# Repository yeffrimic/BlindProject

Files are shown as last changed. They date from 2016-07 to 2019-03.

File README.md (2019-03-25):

# Blind project

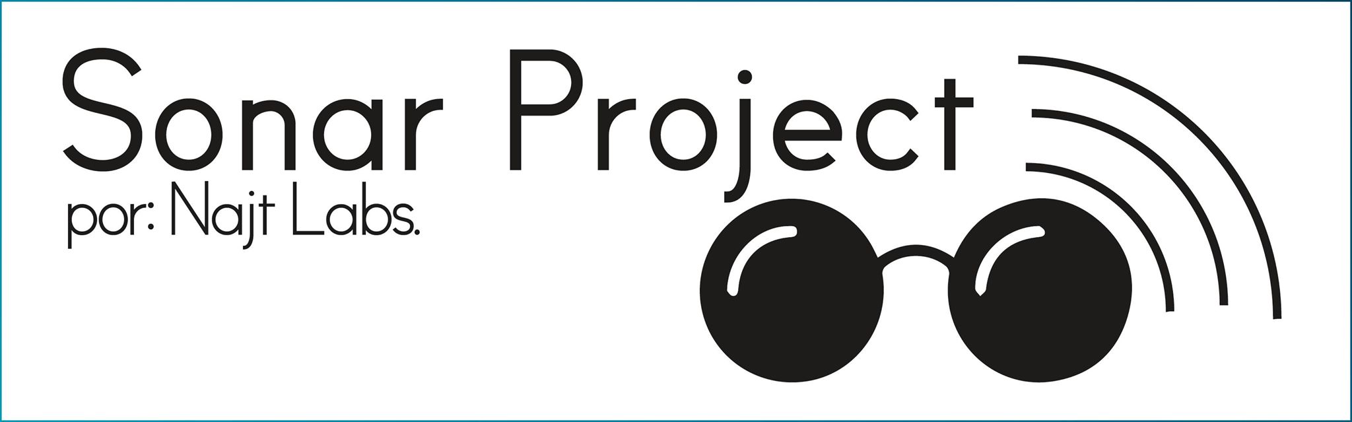
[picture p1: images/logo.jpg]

Is an open project that want to give blind people a new way to feel the world, using an ultrasonic sensor to measure the distance between the device and an obstacle a meter away.
[website](https://yeffrimic.github.io/proyectos/sonar.html)
## Usage
you can use it as a clothespin, just need to put in the clothes.

## Team Members
[Yeffri J. Salazar](https://yeffrimic.github.io) team leader, prototyping.<br>
[Sebastian Juarez](https://jucamake.wordpress.com) 3d design.<br>
[Elmer Colchaj](https://www.facebook.com/E.R.C.G.X) schematic and PCB design.<br>

## Requirements
* [Attiny85.](http://www.ebay.com/itm/10PCS-ATTINY13A-PU-ATTINY13A-DIP8-IC-MCU-AVR-1K-FLASH-20MHZ-ATMEL-NEW-/191674226371)
* [two transistors 2n3904.](http://www.ebay.com/itm/100Pcs-2N3904-TO-92-NPN-General-Purpose-Transistor-/381374819086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)
* [push button two pins.](http://www.ebay.com/itm/100pcs-2pins-Tactile-Push-Button-Switch-Tact-Switch-6X6X5mm-Momentary-/291613157808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)
* [socket 8 pins.](http://www.ebay.com/itm/10PCS-8-Pins-DIP-IC-Sockets-Adaptor-Solder-Type-Socket-/161009224443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)
* [USB cable.](http://www.ebay.com/itm/10Pcs-USB2-0-Type-A-Plug-4-pin-Male-Adapter-Connector-jack-Black-Plastic-Cover-/272041592227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)
* [ultrasonic sensor HC-SR04.](http://www.ebay.com/itm/5pcs-Ultrasonic-Module-HC-SR04-Distance-Measuring-Transducer-Sensor-for-Arduino-/381374789471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)
* [coin vibrator.](http://www.ebay.com/itm/3V-DC-Coin-Sized-Vibration-Motor-10mm-x-3-3mm-x2-Atmel-AVR-Arduino-/131671891439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)

## Installation
Download the sketch and upload the code to an ATtiny 85<br />
tutorial: https://themicrofcontrol.wordpress.com/2016/06/03/como-programar-un-attiny-con-arduino/
Please change the LED2 by the coin vibrator.
##Circuit

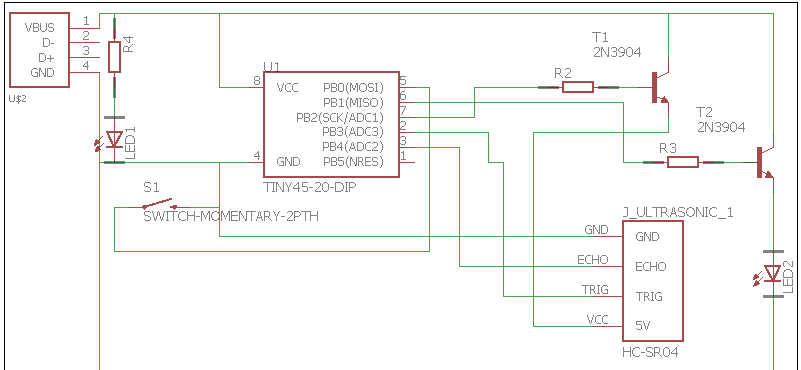
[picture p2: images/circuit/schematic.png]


##Board
 the board was made in proteus by labcenter the file is in the proteus folder
 
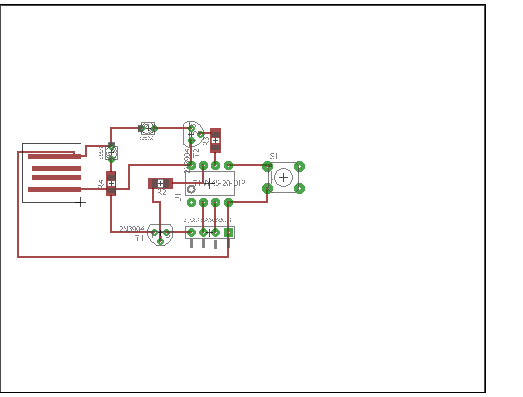
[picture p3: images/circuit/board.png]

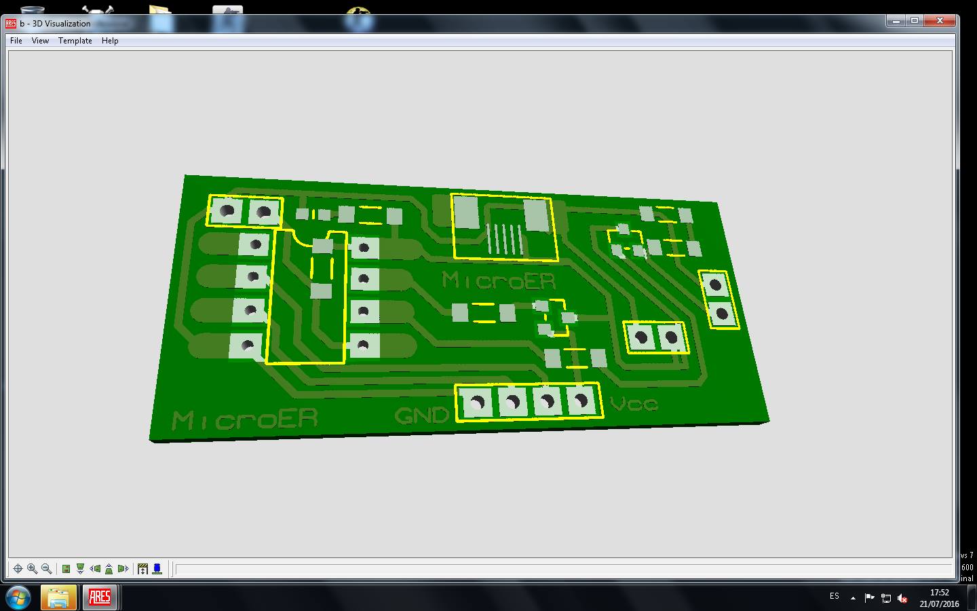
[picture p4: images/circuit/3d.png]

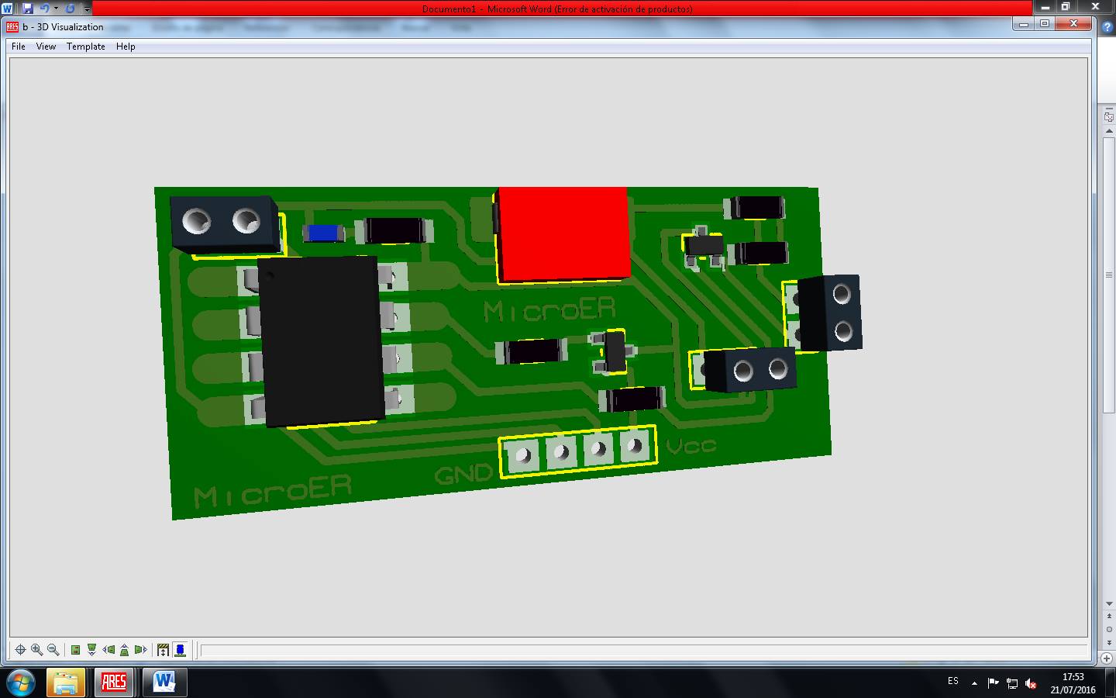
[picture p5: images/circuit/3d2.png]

##Issues

## STL FILES
The files are in the 3d files folder.
[Front] (https://github.com/yeffrimic/BlindProject/blob/master/3d%20files/Pieza1.STL)
[Back] (https://github.com/yeffrimic/BlindProject/blob/master/3d%20files/Pieza2.STL)

## Mounting case
#####Images
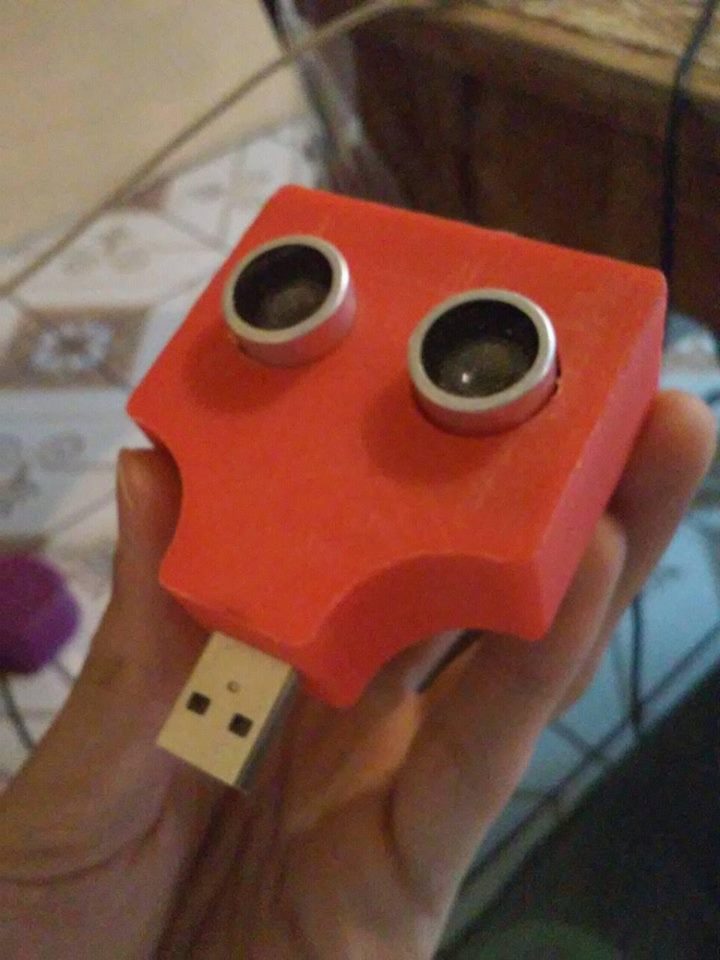
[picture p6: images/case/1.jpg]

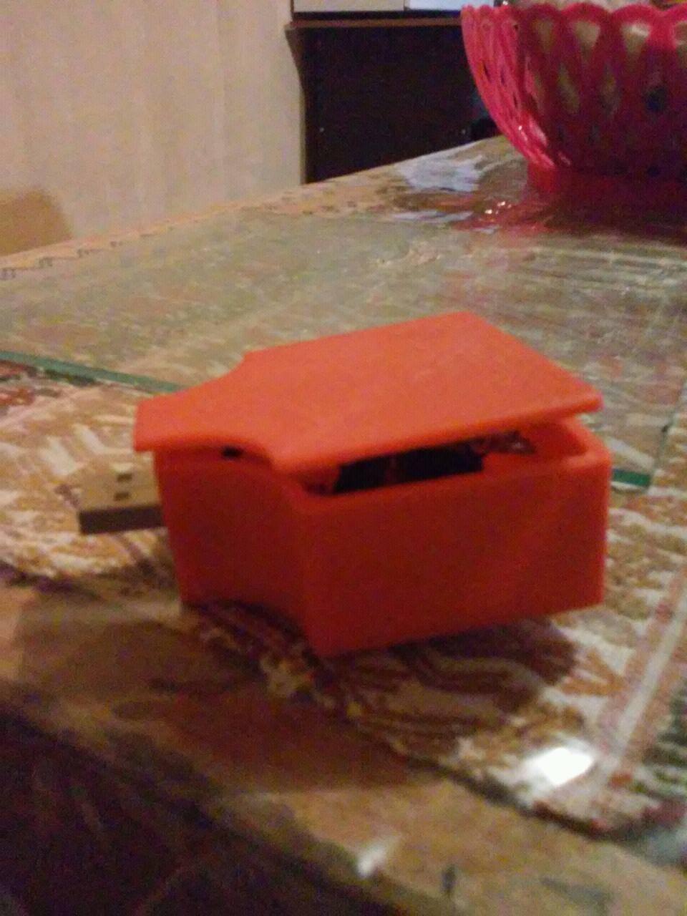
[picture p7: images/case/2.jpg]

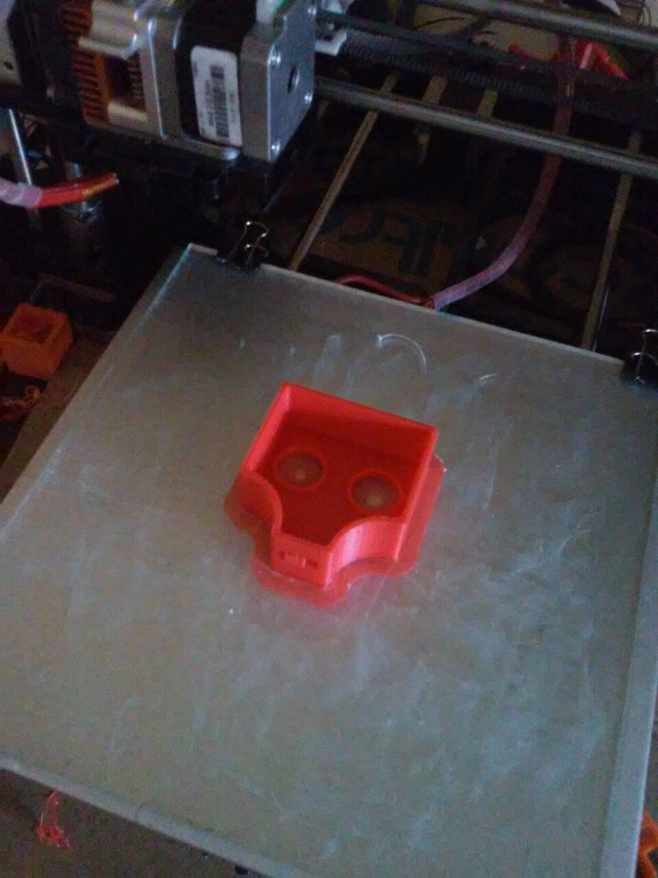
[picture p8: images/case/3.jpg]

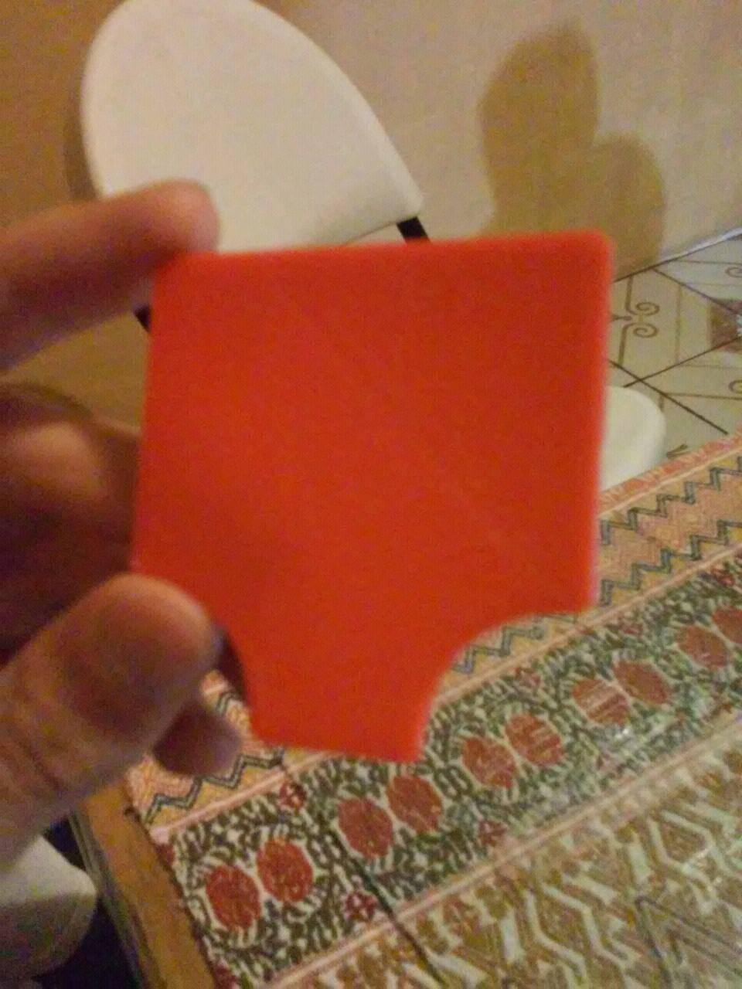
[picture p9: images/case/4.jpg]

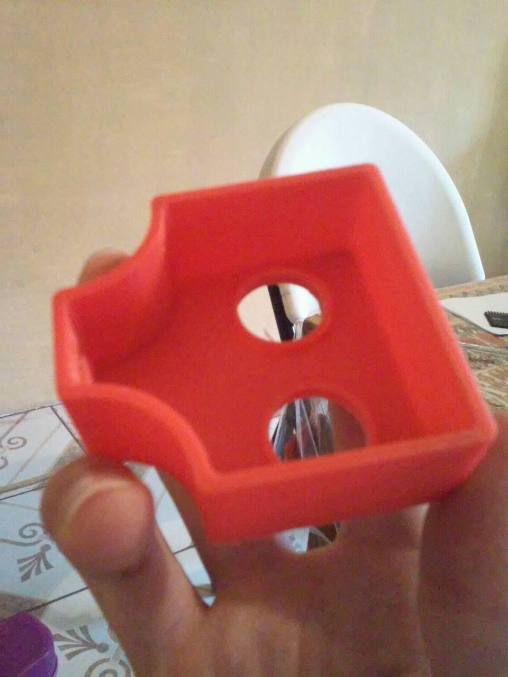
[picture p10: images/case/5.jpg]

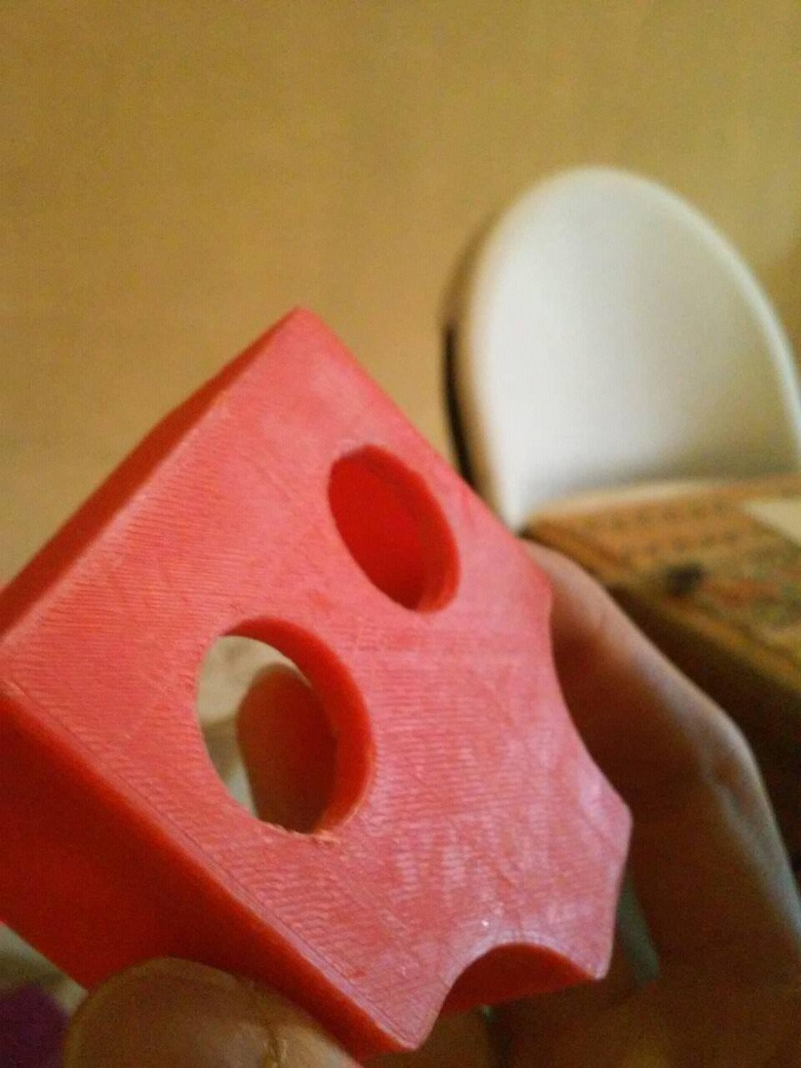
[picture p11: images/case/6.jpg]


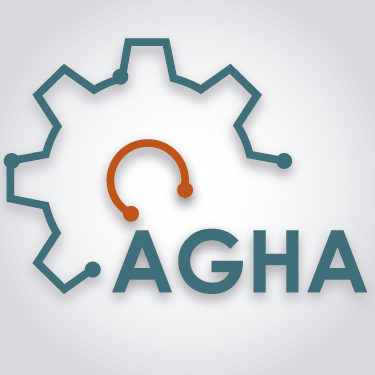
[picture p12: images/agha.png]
### Sonar is part of [AGHA Asociacion Guatemalteca de Hardware Abierto <br> ](https://www.facebook.com/hardwaregt)
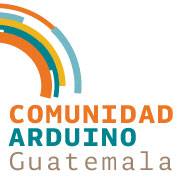
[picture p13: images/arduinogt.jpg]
### Sonar is part of [Comunidad Arduino Guatemala <br> ](https://www.facebook.com/ArduinoGuatemala)
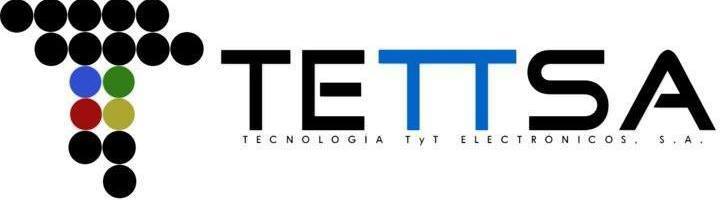
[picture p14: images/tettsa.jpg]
## Sponsored by [TETTSA ](https://www.facebook.com/Electronica-Tettsa-336404033108589/?fref=ts)
<br /><span xmlns:dct="http://purl.org/dc/terms/" property="dct:title">Blind project</span> por <a xmlns:cc="http://creativecommons.org/ns#" href="https://github.com/yeffrimic/BlindProject" property="cc:attributionName" rel="cc:attributionURL">Yeffri salazar</a> se distribuye bajo una <a rel="license" href="http://creativecommons.org/licenses/by-sa/4.0/">Licencia Creative Commons Atribución-CompartirIgual 4.0 Internacional</a>.<br />Basada en una obra en <a xmlns:dct="http://purl.org/dc/terms/" href="https://github.com/yeffrimic/BlindProject/blob/master/blindProject/blindProject.ino" rel="dct:source">https://github.com/yeffrimic/BlindProject/blob/master/blindProject/blindProject.ino</a>.

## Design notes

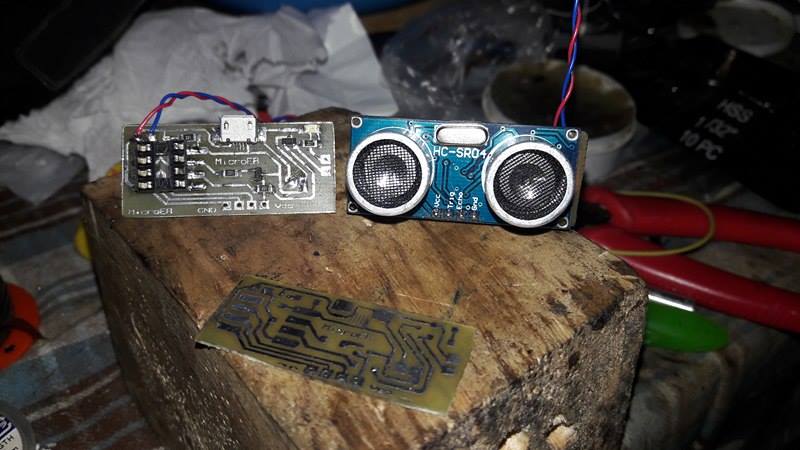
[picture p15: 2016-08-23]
images/circuit/13816998_1175152279173122_1122507406_n.jpg

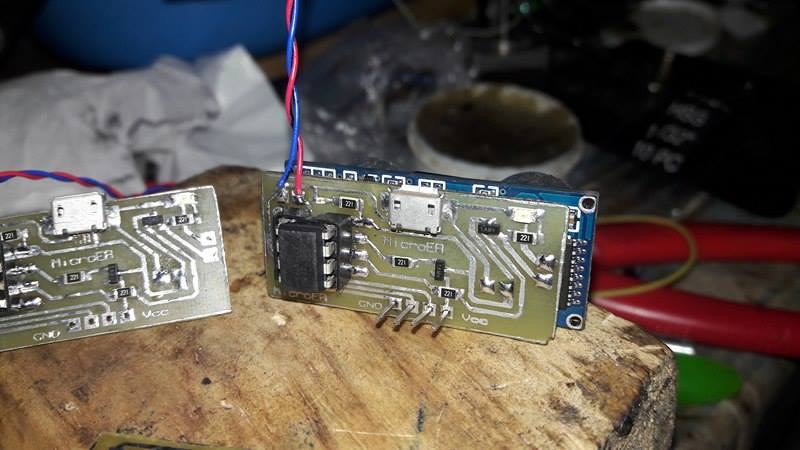
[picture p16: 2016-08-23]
images/circuit/13823134_1175152265839790_208842915_n.jpg

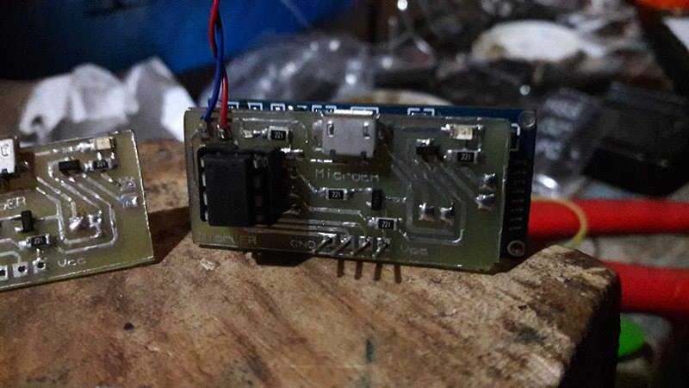
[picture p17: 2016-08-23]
images/circuit/13819323_1175152332506450_1943934899_n.jpg

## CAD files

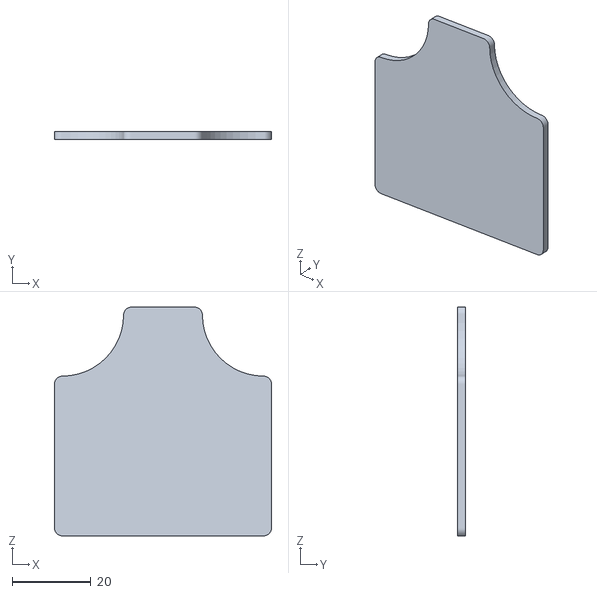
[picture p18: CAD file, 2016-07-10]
3d files/Pieza2v1.STL
55.0 x 2.00 x 58.0

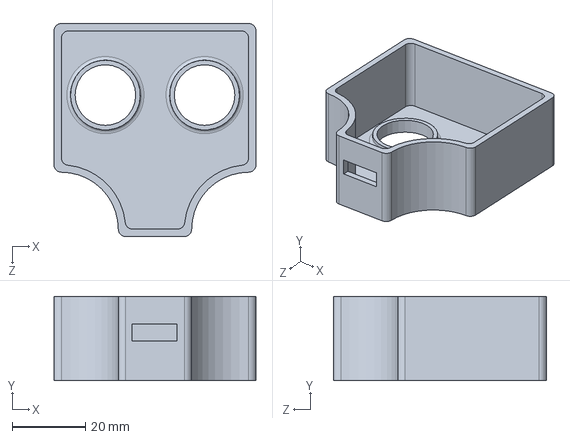
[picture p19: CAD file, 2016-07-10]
3d files/Pieza1.SLDPRT
55.0 x 23.0 x 58.0 mm

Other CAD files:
3d files/Pieza2.SLDPRT
3d files/Pieza1v1.STL
3d files/Pieza1.STL
3d files/Pieza2.STL

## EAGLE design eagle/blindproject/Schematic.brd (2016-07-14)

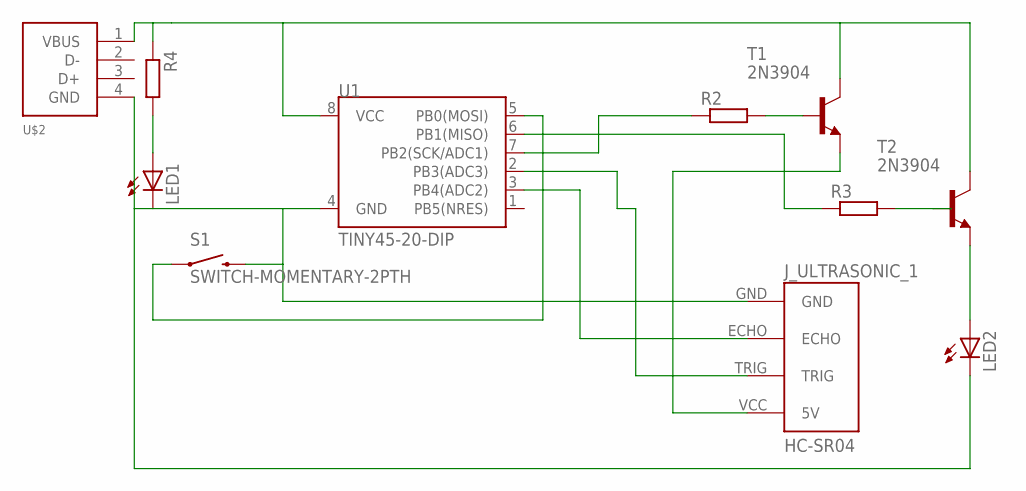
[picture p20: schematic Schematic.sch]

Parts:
J_ULTRASONIC_1: HC-SR04; HC-SR04_FOOTPRINT
LED1, LED2: LED_ELD260; LED_LD260
R2, R3, R4: RR1206; R1206
S1: SWITCH-MOMENTARY-2PTH; TACTILE-PTH
T1, T2: 2N3904; TO92
U1: TINY45-20-DIP; DIP08
U$2: USB-CON-4PIN; USB-MALE-A-PCB

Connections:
unnamed: R2.1, U1.7 (PB2(SCK/ADC1))
unnamed: R3.1, U1.6 (PB1(MISO))
unnamed: LED2.A, T2.3 (E)
unnamed: R4.1, T1.1 (C), T2.1 (C), U1.8 (VCC), U$2.1 (VBUS)
unnamed: R2.2, T1.2 (B)
unnamed: R3.2, T2.2 (B)
unnamed: J_ULTRASONIC_1.GND, LED1.K (C), LED2.K (C), S1.3 (2), U1.4 (GND), U$2.4 (GND)
unnamed: J_ULTRASONIC_1.ECHO, U1.3 (PB4(ADC2))
unnamed: J_ULTRASONIC_1.TRIG, U1.2 (PB3(ADC3))
unnamed: J_ULTRASONIC_1.VCC (5V), T1.3 (E)
unnamed: S1.1, U1.5 (PB0(MOSI))
unnamed: LED1.A, R4.2

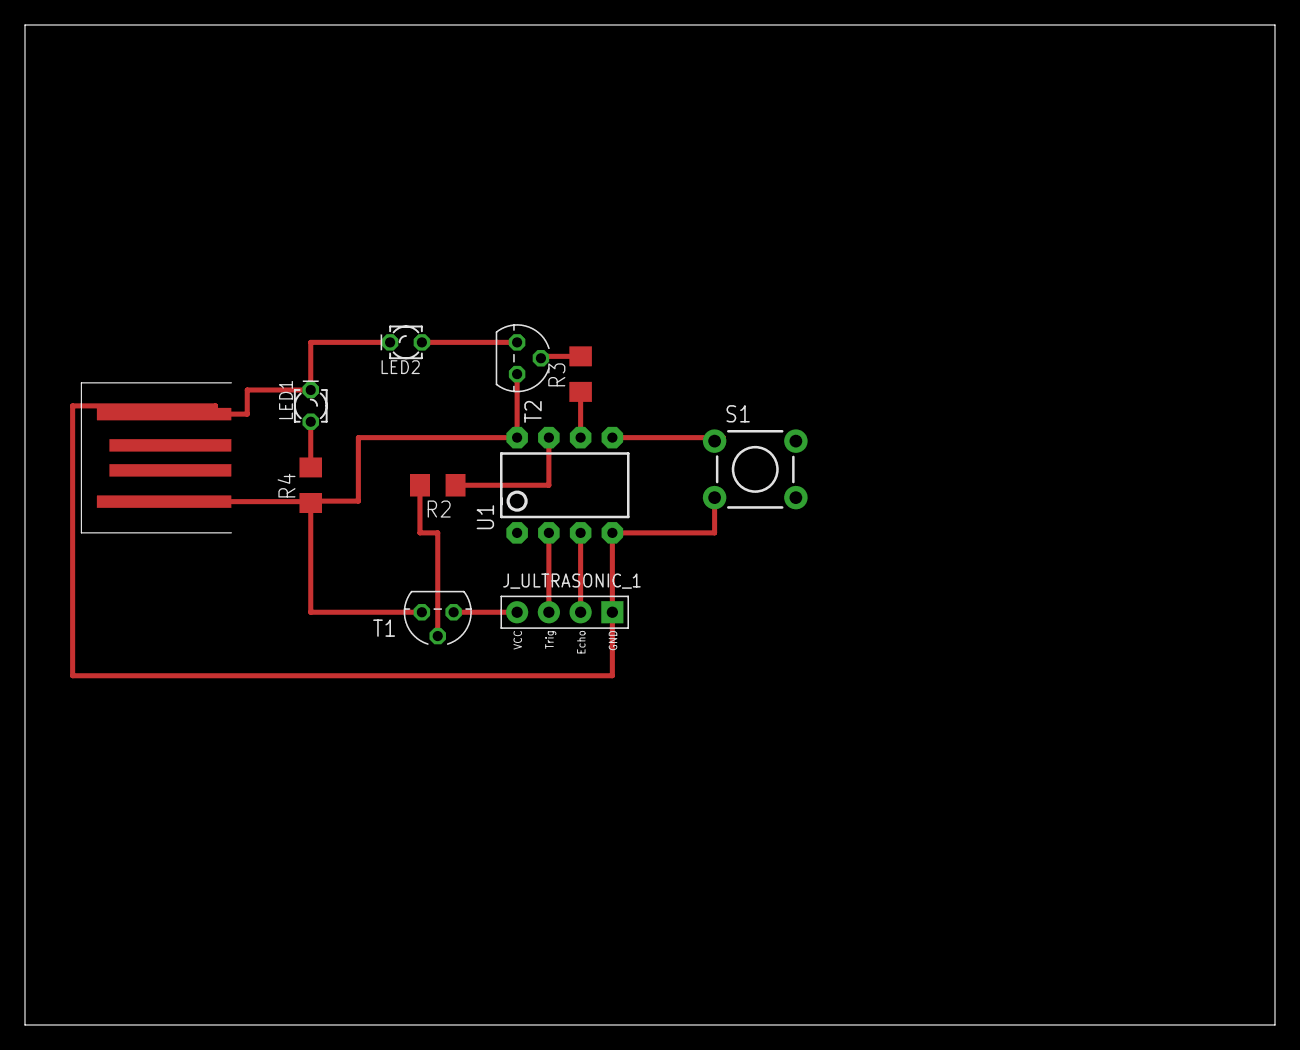
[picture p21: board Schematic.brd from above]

Board: 2 copper layers, 100.0 x 80.0 mm, 11 parts (0 on the bottom side), 12 nets.

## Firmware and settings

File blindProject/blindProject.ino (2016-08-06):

/*
 ******************************
 **      blind Project       **
 **                          **
 ******************************
 *by Yeffri Salazar
 */



#define button 0
#define VccUltrasonicSensor 2
#define iPinTrigger  3 //D1
#define iPinEcho  4 //D2
#define motor 1
void setup() {
  // put your setup code here, to run once:
  pinMode(iPinTrigger, OUTPUT);
  pinMode(motor, OUTPUT);
  pinMode(iPinEcho, INPUT);
  pinMode(VccUltrasonicSensor, OUTPUT);
  pinMode(button, INPUT_PULLUP);
  digitalWrite(motor, LOW);
  digitalWrite(VccUltrasonicSensor, HIGH);
}

void loop() {
  if (digitalRead(button) == LOW) {
    digitalWrite(VccUltrasonicSensor, LOW);
    delay(30000);
    digitalWrite(VccUltrasonicSensor, HIGH);
  }
  int average = ultrasonicsensor();
  if (average < 100) {
    digitalWrite(motor, HIGH);
    delay((average * 3));
    digitalWrite(motor, LOW);
    delay((average * 3));
  }
}

int ultrasonicsensor() {

  digitalWrite(iPinTrigger, LOW);
  digitalWrite(iPinTrigger, HIGH);
  delayMicroseconds(10);
  digitalWrite(iPinTrigger, LOW);


  //Read the data from the sensor
  double fTime = pulseIn(iPinEcho, HIGH);
  //convert to seconds
  fTime = fTime / 1000000;
  double fSpeed = 347.867;
  //Get the distance in meters
  double fDistance = fSpeed * fTime;
  //Convert to centimeters;
  fDistance = fDistance * 100;
  //Get one way distance
  fDistance = fDistance / 2;
  delay(10);
  return fDistance;
}

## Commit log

2016-06-06 new pins 3 echo ,4 trigger, 1 motor.
2016-06-20 update code, new variables, button added, faster
2016-07-10 adding 3d files
    [Pieza1.SLDPRT, Pieza1.STL, Pieza2.SLDPRT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]
2016-07-14 change button and vcc sensor pins
2016-07-14 adding eagle files
    [Schematic.brd, Schematic.sch]
2016-08-06 adding image and layout pcb files
2016-08-30 adding image agha and arduinogt

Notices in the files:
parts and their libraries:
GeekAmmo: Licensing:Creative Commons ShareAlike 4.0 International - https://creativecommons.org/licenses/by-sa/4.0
